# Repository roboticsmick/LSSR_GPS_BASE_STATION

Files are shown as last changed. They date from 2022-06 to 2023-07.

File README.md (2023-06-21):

# LSSR_GPS_BASE_STATION

A portable, low cost GPS Rocket tracking base station. Uses a Teensy 4.1 and Ebytes LORA module to track and display the current GPS coordinates for a HPR rocket launch. Estimated range is 7km.

This was designed and built for my HPR L1 certification launch. Tracking worked perfectly and I was able to successfully monitor the launch of my rocket, then use the GPS coordinates to locate it’s landing point.

LSR_GPS_base_station

LSR_GPS_base_station 2

Parts list:
* Microcontroller – TEENSY 4.1
* RF receiver – EbyteLORA E22-900T22D (set to 915Mhz for Australia)
* GPS – UBLOX NEO_6M (also works with ATGM336H GPS Module)
* 5V Buck Converter – MPM3610 5V at 1.2A
* Compass – GY271 QMC5883 LCD – OLED 128×64
* Battery – 7.4V LIPO with XT30 connection

Version 2 will use a Raspberry Pi Pico RP2040 to bring the overall costs of the board down.

PCB design was done using Fusion 360 electronics. 

PCB printed using JLCPCB.

Case design is lasercut perspex and 3D printed. Modelled using Fusion 360.

Instructions:
When recording GPS coodinates for launch data. 
1. Power using a USB only (do not turn on the toggle switch).
2. Connect to PC using USB. 
3. Use the device manager to identify which COM port the GPS Base Station is connected to.

base_station_device_manager

4. Open putty (don't use the serial monitor in Arduino as it does not allow saving data and has a limited number of rows).
5. Set to serial and change the COM port to match the ID found in the device manager.

putty

6. Base stations should automaticaly pick up the GPS tracker when turned on.
7. The base station will start displaying GPS coordinates on the LCD when it has a fix.
8. SIV = Satellites in view. At least 3 should be in view to get valid data. 
9. When the rocket has landed, save the GPS coordinate data from putty as a CSV. 
10. Copy the last row of the saved data and paste it into Googlemaps. The rocket coordinates should now be available.

If the rocket coordinates were lost:
1. Unplug the USB, and turn on the GPS base station using the toggle switch.
2. Head in the direction of the last known coordinates.
3. When new coordinates are recieved by the base station, the GPS base station should update on the LCD when the rocket is detected. 
4. If you cannot see the rocket, enter the updated coordinates into your phones googlemaps, and you should be able to work out the location in the field.

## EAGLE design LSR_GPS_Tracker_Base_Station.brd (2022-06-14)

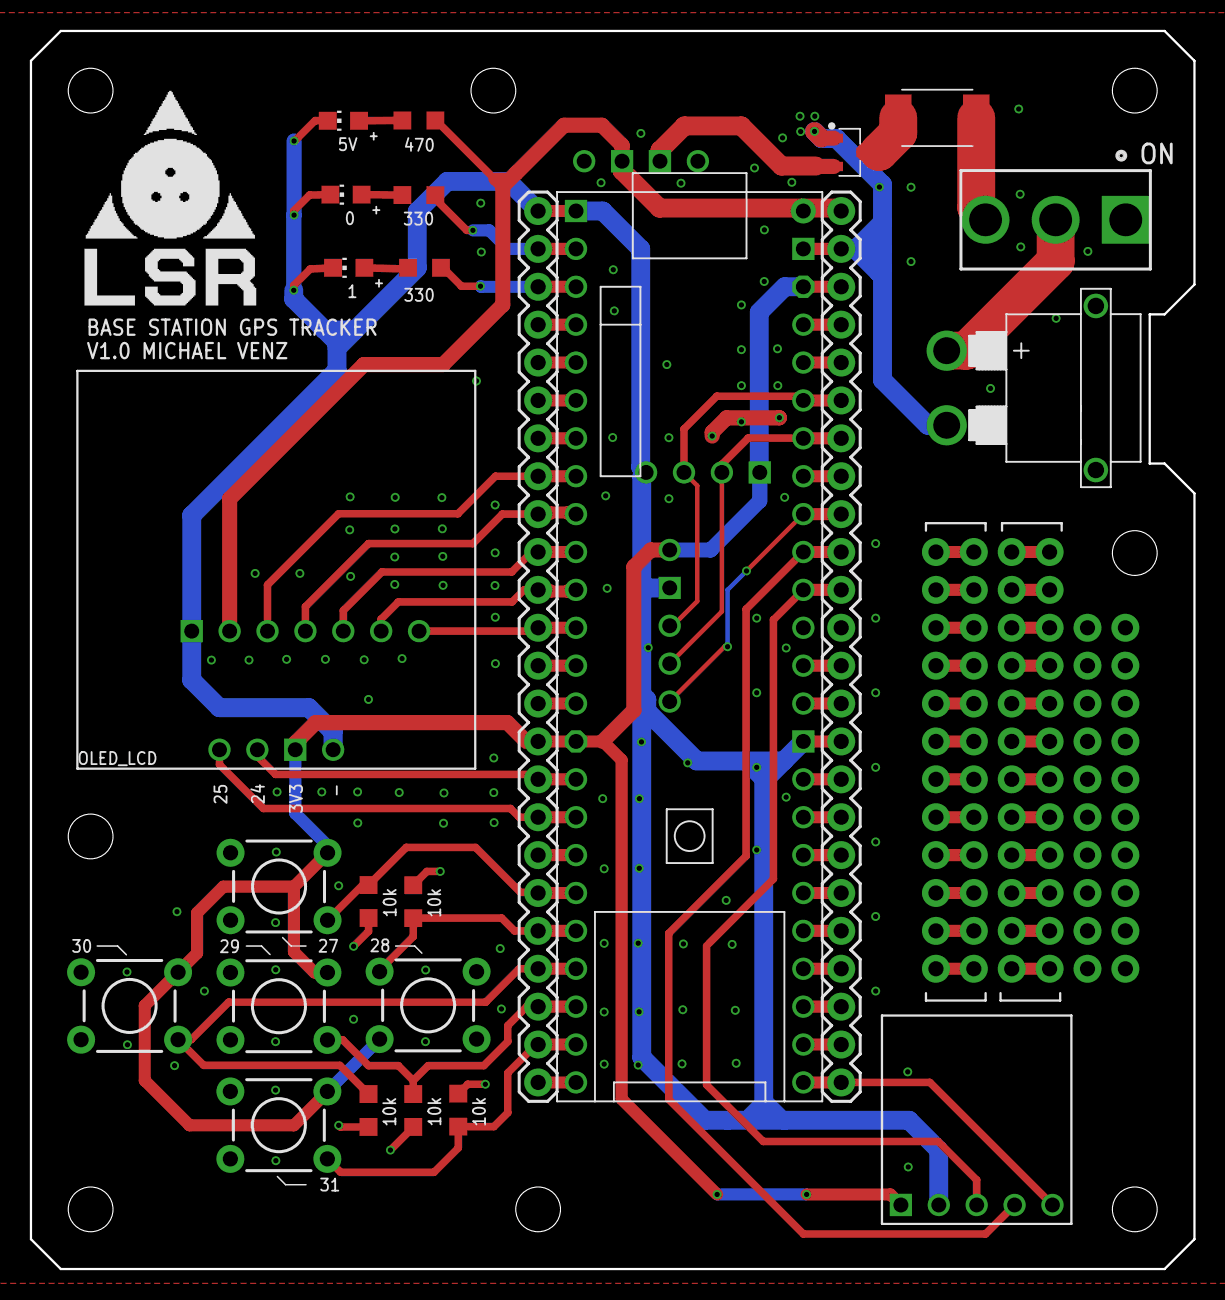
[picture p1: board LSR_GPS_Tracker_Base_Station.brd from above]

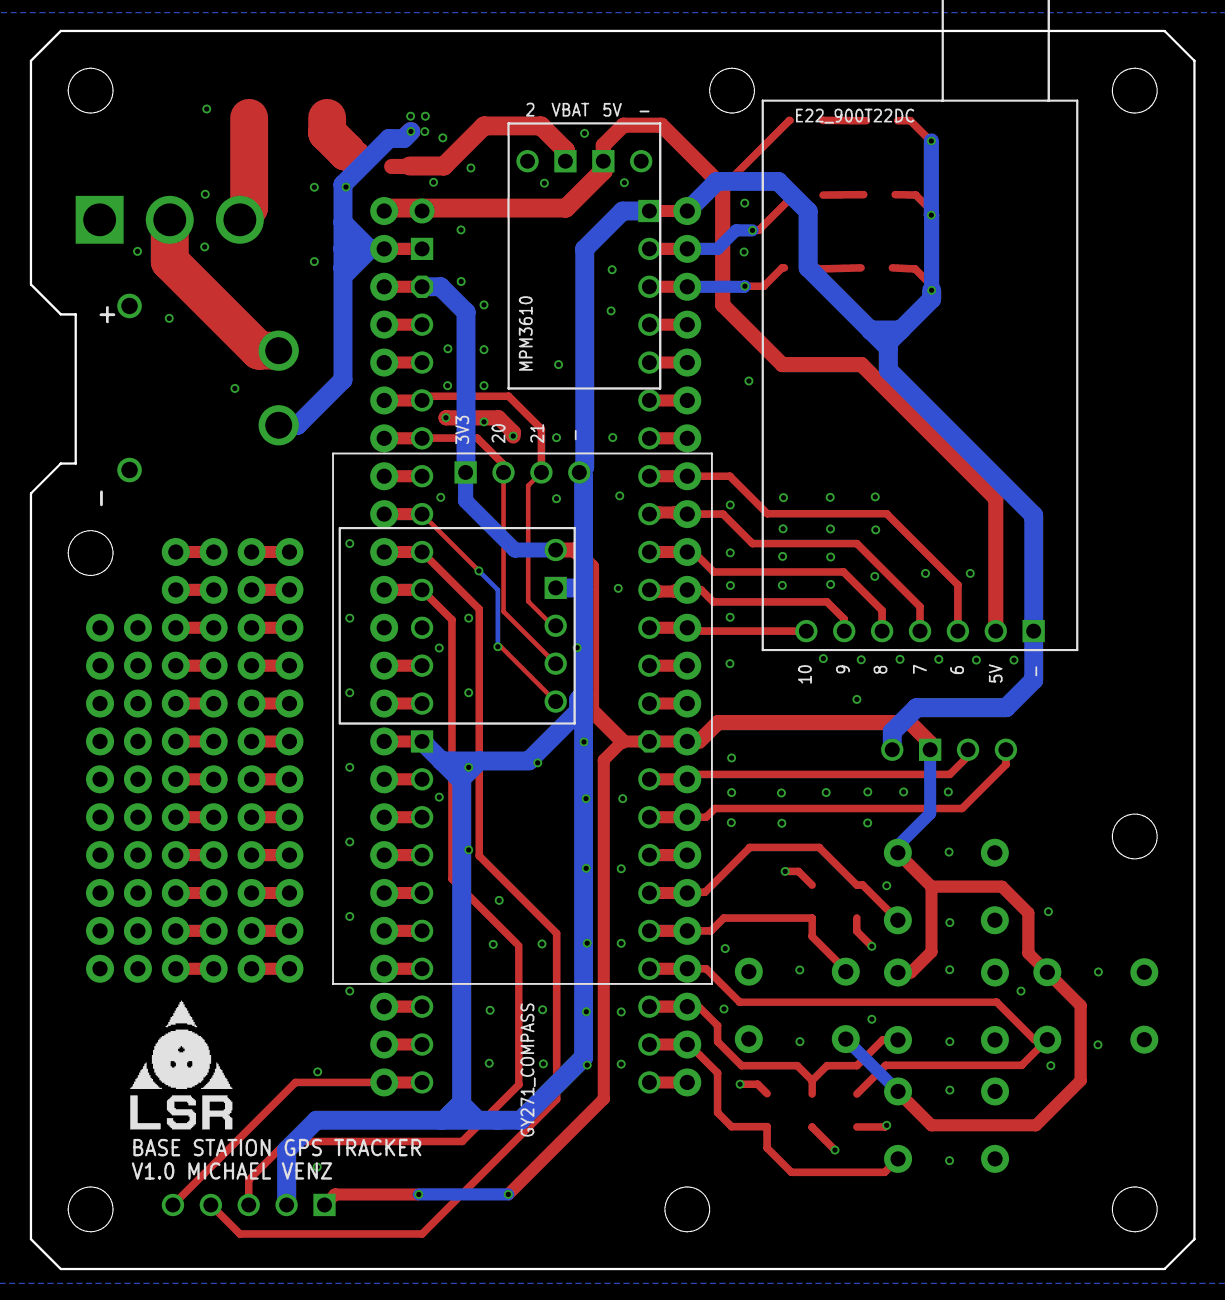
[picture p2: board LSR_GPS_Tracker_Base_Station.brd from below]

Board: 2 copper layers, 78.0 x 83.0 mm, 37 parts (5 on the bottom side), 76 nets.

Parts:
COMP1: GY271_QMC5883_COMPASS_MOD; GY271_QMC5883_COMPASS_MOD_FP
CON1: XT30PW-M; XT30PW-PLUG
F1: 1812L200/12; FUSC4532X125
GPS1: NEO_6M_0_001_MOD; NEO_6M_0_001_MOD_FP
J1, J2: 1X24
J3, J4, J5, J6: 1X12_NO_SILK
J7, J8: 1X10_NO_SILK
LED1, LED2, LED3: LED; 0805_LED
PS1: MPM3610_5V_1A2_MOD; MPM3610_5V_1A2_FP
R7, R8, R9, R10, R11: 10k; 0805_RESISTOR_FP
R15, R16, R17: 470; 0805_RESISTOR_FP
RF1: E22_900T22D_MOD; E22_900T22D_MOD_FP
S1, S2, S3, S4, S5: MOMENTARY-SWITCH-SPST-PTH-6.0MM; TACTILE_SWITCH_PTH_6.0MM
S6: 1101M2S3CQE2; SW_1101M2S3CQE2
SSM3J372R,LF: PNP; SOT95P237X112-3N
U$1: OLED_LCD_128_64_MOD; OLED_LCD_128_64_MOD_FP
U$2: LSR_LOGO_TEXT_200PX_FP
U$3: TEENSY_4_1; TEENSY_4_1_FP
U$4: GPS_ATGM336H_MOD; GPS_ATGM336H_FP
U$5: LSR_LOGO_TEXT_120PX_FP

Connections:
3.3V: COMP1.VCC, GPS1.VCC, J1.4, J2.11, S1.3, S2.3, S3.3, S4.3, S5.3, U$1.VCC, U$3.3V3-1, U$3.3V3-3, U$4.VCC
5V: J1.2, PS1.5V, R15.1, RF1.5V, U$3.VIN
BUTT_01: J2.7, R7.1, S1.1, U$3.27-A13/SCK1
BUTT_02: J2.6, R8.1, S2.1, U$3.28-RX7/PWM28
BUTT_03: J2.4, R9.1, S3.1, U$3.30-CRX3
BUTT_04: J2.5, R10.1, S4.1, U$3.29-TX7/PWM29
BUTT_05: J2.3, R11.1, S5.1, U$3.31-CTX3
COMP_DRDY: COMP1.DRDY, J1.25, U$3.33-MCLK2/PWM33
COMP_SCL: COMP1.SCL, J1.12, U$3.16-A2/RX4/SCL1
COMP_SDA: COMP1.SDA, J1.11, U$3.17-A3/TX4/SDA1
GND: COMP1.GND, CON1.-, GPS1.GND, J1.3, J1.16, J2.25, LED1.C, LED2.C, LED3.C, PS1.G, R7.2, R8.2, R9.2, R10.2, R11.2, RF1.GND, S6.1, SSM3J372R,LF.1, U$1.GND, U$3.GND1, U$3.GND3, U$3.GND6, U$4.GND
GPS_PPS: J1.10, U$3.18-A4/SDA0/PWM18, U$4.PPS
GPS_RX: GPS1.RX, J1.8, U$3.20-A6/TX5/LRCLK1, U$4.RX
GPX_TX: GPS1.TX, J1.7, U$3.21-A7/RX5/BCLK1, U$4.TX
LED1: J2.24, R16.1, U$3.0-RX1/CS1/CRX2/PWM00
LED2: J2.23, R17.1, U$3.1-TX1/MISO1/CTX2/PW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
unnamed: J1.5, U$3.23-A9/CRX1/MCLK1/PW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
unnamed: J1.6, U$3.22-A8/CTX1/PWM22
unnamed: J1.13, U$3.15-A1/RX3/SPDIF_IN/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
unnamed: J3.12, J4.12
unnamed: J2.2, U$3.32-OUT1B
unnamed: J1.14, U$3.14-A0/TX3/SPDIF_OUT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
unnamed: J1.15, U$3.13-SCK/LED/PWM13
unnamed: J1.17, U$3.41-A17/MISO1
unnamed: J1.18, U$3.40-A16/CS1
unnamed: J1.19, U$3.39-A15/CS/OUT1A
unnamed: J1.20, U$3.38-A14/CS/IN1
unnamed: J1.21, U$3.37-CS/PWM37
unnamed: J1.22, U$3.36-CS/PWM36
unnamed: J1.23, U$3.35-TX8
unnamed: J1.24, U$3.34-RX8
unnamed: J3.11, J4.11
unnamed: J3.10, J4.10
unnamed: J1.9, U$3.19-A5/SCL0/PWM19
unnamed: J2.21, U$3.3-LRCLK2/PWM03
unnamed: J2.20, U$3.4-BCLK2/PWM04
unnamed: J2.19, U$3.5-IN2/PWM05
unnamed: J2.13, U$3.11-MOSI/CTX1/PWM11
unnamed: J2.12, U$3.12-MISO/MQSL/PWM12
unnamed: J3.9, J4.9
unnamed: J2.8, U$3.26-A12/MOSI1
unnamed: J3.8, J4.8
unnamed: J2.22, U$3.2-OUT2/PWM02
unnamed: J3.7, J4.7
unnamed: J3.6, J4.6
unnamed: J3.5, J4.5
unnamed: LED3.A, R15.2
unnamed: LED1.A, R16.2
unnamed: J3.4, J4.4
unnamed: J3.3, J4.3
unnamed: J3.2, J4.2
unnamed: J3.1, J4.1
unnamed: J5.12, J6.12
unnamed: J5.11, J6.11
unnamed: J5.10, J6.10
unnamed: J5.9, J6.9
unnamed: F1.2, S6.3
unnamed: F1.1, SSM3J372R,LF.3
unnamed: PS1.VIN, SSM3J372R,LF.2
unnamed: J5.8, J6.8
unnamed: J5.7, J6.7
unnamed: J5.6, J6.6
unnamed: J5.5, J6.5
unnamed: J5.4, J6.4
unnamed: J5.3, J6.3
unnamed: J5.2, J6.2
unnamed: J5.1, J6.1
unnamed: LED2.A, R17.2
OLED_SCL: J2.10, U$1.SCL, U$3.24-A10/TX6/SCL2/PWM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
OLED_SDA: J2.9, U$1.SDA, U$3.25-A11/RX6/SDA2/PWM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
RF_AUX: J2.18, RF1.AUX, U$3.6-OUT1D/PWM06
RF_MODE0: J2.14, RF1.M0, U$3.10-CS\MQSR/PWM10
RF_MODE1: J2.15, RF1.M1, U$3.9-OUT1C/PWM09
RF_RX: J2.16, RF1.RX, U$3.8-TX2/IN1/PWM08
RF_TX: J2.17, RF1.TX, U$3.7-RX2/OUT1A/PWM07
V_BATT: CON1.+, S6.2

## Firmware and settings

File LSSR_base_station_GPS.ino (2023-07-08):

/*
  This code for for the receiver
  Connections
  Module      Teensy/LORA
  M0          10
  M1          9
  Rx          # (This is the MCU Tx line)
  Tx          # (MCU Rx line)
  Aux         6
  Vcc         5V
  Gnd         Gnd

  Module      Sparfun ZOE-M8Q
  SDA         # 
  SCL         # 
  Vcc         3V3
  Gnd         Gnd
*/

#include "EBYTE.h"
#include <Wire.h>
#include <Adafruit_GFX.h>
#include <Adafruit_SSD1306.h>
#include <Adafruit_I2CDevice.h>
#include <elapsedMillis.h>
#include <Bounce2.h>
#include <SoftwareSerial.h>

// Connect to any of the Teensy Serial ports
#define ESerial Serial2
#define gpsPort Serial5

#define SCREEN_WIDTH 128    // OLED display width, in pixels
#define SCREEN_HEIGHT 64    // OLED display height, in pixels
#define I2C_COMP_ADDRESS 0x1E // 0x1E 0011110b, I2C 7bit address of HMC5883

#define PIN_M0 10
#define PIN_M1 9
#define PIN_AX 6
int LED0 = 0;          // LED0
int LED1 = 1;         // LED1
int LEFTBUTTON = 29;
int UPBUTTON = 27;
int RIGHTBUTTON = 28;
int DOWNBUTTON = 30;
int MIDDLEBUTTON = 31;
int buttonDebounce = 5; // Debounce time

// Declaration for an SSD1306 display connected to I2C (SDA, SCL pins)
#define OLED_RESET 4 // Reset pin # (or -1 if sharing Arduino reset pin)
Adafruit_SSD1306 display(SCREEN_WIDTH, SCREEN_HEIGHT, &Wire2, OLED_RESET);

// GPS packet
struct DATA {
  long lat;
  long lon;
  long alt;
  byte SIV;
};


DATA GPSData;
int Chan;
unsigned long Last;

// Button debounce initialise
Bounce leftButton = Bounce();
Bounce upButton = Bounce();
Bounce rightButton = Bounce();
Bounce downButton = Bounce();
Bounce middleButton = Bounce();

// create the transceiver object, passing in the serial and pins
EBYTE Transceiver(&ESerial, PIN_M0, PIN_M1, PIN_AX);

// Logo
#define LOGO_HEIGHT 64
#define LOGO_WIDTH 128
static const unsigned char PROGMEM logo_bmp[] =
  {
    0xff, 0xff, 0xff, 0xff, 0xff, 0xff, 0xff, 0xff, 0xff, 0xff, 0xff, 0xff, 0xff, 0xff, 0xff, 0xff,
    0xff, 0xff, 0xff, 0xff, 0xff, 0xff, 0xff, 0xff, 0xff, 0xff, 0xff, 0xff, 0xff, 0xff, 0xff, 0xff,
    0xff, 0xff, 0xff, 0xff, 0xff, 0xff, 0xff, 0xff, 0xff, 0xff, 0xff, 0xff, 0xff, 0xff, 0xff, 0xff,
    0xff, 0xff, 0xff, 0xff, 0xff, 0xff, 0xff, 0xff, 0xff, 0xff, 0xff, 0xff, 0xff, 0xff, 0xff, 0xff,
    0xff, 0xff, 0xff, 0xff, 0xff, 0xff, 0xff, 0xff, 0xff, 0xff, 0xff, 0xff, 0xff, 0xff, 0xff, 0xff,
    0xff, 0xff, 0xff, 0xff, 0xff, 0xff, 0xff, 0xff, 0xff, 0xff, 0xff, 0xff, 0xff, 0xff, 0xff, 0xff,
    0xff, 0xff, 0xff, 0xff, 0xff, 0xff, 0xff, 0xff, 0xff, 0xff, 0xff, 0xff, 0xff, 0xff, 0xff, 0xff,
    0xff, 0xff, 0xff, 0xff, 0xff, 0xff, 0xff, 0xff, 0xff, 0xff, 0xff, 0xff, 0xff, 0xff, 0xff, 0xff,
    0xff, 0xff, 0xff, 0xff, 0xff, 0xff, 0xff, 0xff, 0xff, 0xff, 0xff, 0xff, 0xff, 0xff, 0xff, 0xff,
    0xff, 0xff, 0xff, 0xff, 0xff, 0xff, 0xff, 0xff, 0xff, 0xff, 0xff, 0xff, 0xff, 0xff, 0xff, 0xff,
    0xff, 0xff, 0xff, 0xff, 0xff, 0xff, 0xff, 0xff, 0xff, 0xff, 0xff, 0xff, 0xff, 0xff, 0xff, 0xff,
    0xff, 0xff, 0xff, 0xff, 0xff, 0xff, 0xff, 0xff, 0xff, 0xff, 0xff, 0xff, 0xff, 0xff, 0xff, 0xff,
    0xff, 0xff, 0xff, 0xff, 0xff, 0xff, 0xff, 0xff, 0xff, 0xff, 0xff, 0xff, 0xff, 0xff, 0xff, 0xff,
    0xff, 0xff, 0xff, 0xff, 0xff, 0xff, 0xff, 0xff, 0xff, 0xff, 0xff, 0xff, 0xff, 0xff, 0xff, 0xff,
    0xff, 0xff, 0xff, 0xff, 0xff, 0xff, 0xff, 0xff, 0x7f, 0xff, 0xff, 0xff, 0xff, 0xff, 0xff, 0xff,
    0xff, 0xff, 0xff, 0xff, 0xff, 0xff, 0xff, 0xff, 0x7f, 0xff, 0xff, 0xff, 0xff, 0xff, 0xff, 0xff,
    0xff, 0xff, 0xff, 0xff, 0xff, 0xff, 0xff, 0xfe, 0x3f, 0xff, 0xff, 0xff, 0xff, 0xff, 0xff, 0xff,
    0xff, 0xff, 0xff, 0xff, 0xff, 0xff, 0xff, 0xfc, 0x1f, 0xff, 0xff, 0xff, 0xff, 0xff, 0xff, 0xff,
    0xff, 0xff, 0xff, 0xff, 0xff, 0xff, 0xff, 0xfc, 0x1f, 0xff, 0xff, 0xff, 0xff, 0xff, 0xff, 0xff,
    0xff, 0xff, 0xff, 0xff, 0xff, 0xff, 0xff, 0xf8, 0x0f, 0xff, 0xff, 0xff, 0xff, 0xff, 0xff, 0xff,
    0xff, 0xff, 0xff, 0xff, 0xff, 0xff, 0xff, 0xf8, 0x0f, 0xff, 0xff, 0xff, 0xff, 0xff, 0xff, 0xff,
    0xff, 0xff, 0xff, 0xff, 0xff, 0xff, 0xff, 0xf0, 0x07, 0xff, 0xff, 0xff, 0xff, 0xff, 0xff, 0xff,
    0xff, 0xff, 0xff, 0xff, 0xff, 0xff, 0xff, 0xf3, 0xe7, 0xff, 0xff, 0xff, 0xff, 0xff, 0xff, 0xff,
    0xff, 0xff, 0xff, 0xff, 0xff, 0xff, 0xff, 0xff, 0xff, 0xff, 0xff, 0xff, 0xff, 0xff, 0xff, 0xff,
    0xff, 0xff, 0xff, 0xff, 0xff, 0xff, 0xff, 0xf8, 0x0f, 0xff, 0xff, 0xff, 0xff, 0xff, 0xff, 0xff,
    0xff, 0xff, 0xff, 0xff, 0xff, 0xff, 0xff, 0xe0, 0x03, 0xff, 0xff, 0xff, 0xff, 0xff, 0xff, 0xff,
    0xff, 0xff, 0xff, 0xff, 0xff, 0xff, 0xff, 0xc0, 0x01, 0xff, 0xff, 0xff, 0xff, 0xff, 0xff, 0xff,
    0xff, 0xff, 0xff, 0xff, 0xff, 0xff, 0xff, 0x80, 0x00, 0xff, 0xff, 0xff, 0xff, 0xff, 0xff, 0xff,
    0xff, 0xff, 0xff, 0xff, 0xff, 0xff, 0xff, 0x00, 0x00, 0x7f, 0xff, 0xff, 0xff, 0xff, 0xff, 0xff,
    0xff, 0xff, 0xff, 0xff, 0xff, 0xff, 0xff, 0x00, 0x00, 0x7f, 0xff, 0xff, 0xff, 0xff, 0xff, 0xff,
    0xff, 0xff, 0xff, 0xff, 0xff, 0xff, 0xfe, 0x00, 0x80, 0x3f, 0xff, 0xff, 0xff, 0xff, 0xff, 0xff,
    0xff, 0xff, 0xff, 0xff, 0xff, 0xff, 0xfe, 0x00, 0x00, 0x3f, 0xff, 0xff, 0xff, 0xff, 0xff, 0xff,
    0xff, 0xff, 0xff, 0xff, 0xff, 0xff, 0xfe, 0x00, 0x00, 0x3f, 0xff, 0xff, 0xff, 0xff, 0xff, 0xff,
    0xff, 0xff, 0xff, 0xff, 0xff, 0xff, 0xfe, 0x00, 0x00, 0x3f, 0xff, 0xff, 0xff, 0xff, 0xff, 0xff,
    0xff, 0xff, 0xff, 0xff, 0xff, 0xff, 0xfe, 0x00, 0x00, 0x3f, 0xff, 0xff, 0xff, 0xff, 0xff, 0xff,
    0xff, 0xff, 0xff, 0xff, 0xff, 0xff, 0xf2, 0x06, 0x30, 0x27, 0xff, 0xff, 0xff, 0xff, 0xff, 0xff,
    0xff, 0xff, 0xff, 0xff, 0xff, 0xff, 0xf2, 0x00, 0x00, 0x27, 0xff, 0xff, 0xff, 0xff, 0xff, 0xff,
    0xff, 0xff, 0xff, 0xff, 0xff, 0xff, 0xe3, 0x00, 0x00, 0x63, 0xff, 0xff, 0xff, 0xff, 0xff, 0xff,
    0xff, 0xff, 0xff, 0xff, 0xff, 0xff, 0xe3, 0x00, 0x00, 0x63, 0xff, 0xff, 0xff, 0xff, 0xff, 0xff,
    0xff, 0xff, 0xff, 0xff, 0xff, 0xff, 0xc1, 0x80, 0x00, 0xc1, 0xff, 0xff, 0xff, 0xff, 0xff, 0xff,
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
};


void drawlogo(void)
{
  display.clearDisplay();
  display.drawBitmap(
    (display.width() - LOGO_WIDTH) / 2,
    (display.height() - LOGO_HEIGHT) / 2,
    logo_bmp, LOGO_WIDTH, LOGO_HEIGHT, 1);
  display.display();
  delay(1000);
  // Invert and restore display, pausing in-between
  display.invertDisplay(true);
  delay(1000);
  display.invertDisplay(false);
  delay(1000);
  display.clearDisplay();
}

void printtext(void)
{
  display.clearDisplay();

  display.setTextSize(1);        // Normal 1:1 pixel scale
  display.setTextColor(SSD1306_WHITE); // Draw white text
  display.setCursor(0, 0);       // Start at top-left corner
  display.cp437(true);         // Use full 256 char 'Code Page 437' font

  display.print("Lat: ");
  display.print(GPSData.lat / 10000000., 7);
  display.print("\n");
  display.print("Lon: ");
  display.print(GPSData.lon / 10000000., 7);
  display.print("\n");
  display.print("Alt: ");
  display.print(GPSData.alt / 1000., 2);
  display.print("\n");
  display.print("SIV: ");
  display.print(GPSData.SIV);
  
  display.display();
}


void setup() {

  Serial.begin(9600);

  // wait for the serial to connect
//  while (!Serial) {}

  // start the transceiver serial port--i have yet to get a different
  // baud rate to work--data sheet says to keep on 9600

  ESerial.begin(9600);

  // this init will set the pinModes for you
  Transceiver.init();

  // SSD1306_SWITCHCAPVCC = generate display voltage from 3.3V internally
  if (!display.begin(SSD1306_SWITCHCAPVCC, 0x3C))
  { // Address 0x3D for 128x64
    Serial.println(F("SSD1306 allocation failed"));
    for (;;)
      ; // Don't proceed, loop forever
  }
  display.setRotation(2); // Rotates screen 180 degrees
  drawlogo();       // Draw LSR Logo
  delay(2000);
  display.clearDisplay(); // Clear the buffer

  pinMode(LED0, OUTPUT); // Set 0 as LED output
  pinMode(LED1, OUTPUT); // Set 1 as LED output

  // Button Setup and Debounce
  pinMode(LEFTBUTTON, INPUT); // Left button
  leftButton.attach(LEFTBUTTON);
  leftButton.interval(buttonDebounce);

  pinMode(UPBUTTON, INPUT); // Left button
  upButton.attach(UPBUTTON);
  upButton.interval(buttonDebounce);

  pinMode(RIGHTBUTTON, INPUT); // Left button
  rightButton.attach(RIGHTBUTTON);
  rightButton.interval(buttonDebounce);

  pinMode(DOWNBUTTON, INPUT); // Left button
  downButton.attach(DOWNBUTTON);
  downButton.interval(buttonDebounce);

  pinMode(MIDDLEBUTTON, INPUT); // Left button
  middleButton.attach(MIDDLEBUTTON);
  middleButton.interval(buttonDebounce);

}

void loop() {
  
  // If the transceiver serial is available, process incoming data
  // you can also use ESerial.available()
  if (Transceiver.available()) {

    digitalWrite(LED0, HIGH);

    // Read transciever data
    Transceiver.GetStruct(&GPSData, sizeof(GPSData));

    if (GPSData.SIV >= 3) {
      digitalWrite(LED1, HIGH);
    } 
    else {
      digitalWrite(LED1, LOW);
    }

    // Convert to googlemaps coordinates 
    Serial.print(GPSData.lat / 10000000., 7);
    Serial.print(F(", "));
    Serial.print(GPSData.lon / 10000000., 7);
    Serial.print(F(", "));
    Serial.print(GPSData.alt / 1000., 2);
    Serial.print(F(", "));
    Serial.print(GPSData.SIV);
    Serial.println();
  
    printtext();
    
    // if you got data, update the checker
    Last = millis();
  }
  else {
    // if the time checker is over some prescribed amount
    // let the user know there is no incoming data
    if ((millis() - Last) > 200) {
      digitalWrite(LED0, LOW);
      Last = millis();
    }
  }
}

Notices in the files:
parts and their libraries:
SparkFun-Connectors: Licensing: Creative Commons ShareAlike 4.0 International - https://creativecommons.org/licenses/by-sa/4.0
